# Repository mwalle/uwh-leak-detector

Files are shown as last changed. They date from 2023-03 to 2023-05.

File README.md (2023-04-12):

# Underwater Housing Leak Detector

Monitors the underpressure of your underwater housing and notifies you of
any leaks.

## Features

The leak detector provides the following features:

- Optical and acoustical alarm. Red and green LED to indicate the current
  health. Piezo buzzer to get the user's attention.
- Powered by just one CR2032 coin cell.
- Very long battery life, works down to 1.8V cell voltage.
- Battery monitoring. Indicates low-battery during idle mode.
- Hackable design using a Microchip ATtiny microcontroller
- MEMS pressure sensor. Supports two different devices: Bosch BMP581 and
  STMicro LPS22HB.
- Demo mode. Test any changes by a simulated sensor.
- Optical UART debug mode. The red LED can be used as a serial port. The
  receiver consists of a photo transistor and a bipolar transistor in a
  darlington configuration and an UART-to-USB adapter.
- Different modes selectable by the reset button.
- Extremely small.
- Open Hardware and Open Firmware schematics and layout as well as firmware
  sources are free for everyone.

## User's manual

TBD

## Mode of operation

Most functionality revolves around the microcontroller polling the pressure
sensor at a low frequency and then go (back) to sleep. The goal is to be in
sleep mode most of the time to save precious battery power. The
microcontroller runs with a system clock of 1MHz. The assumption is that a
slower clock frequency will preserve more power. But it is not clear whether
this is true; it might as well save more power if the microcontroller can
go back to sleep faster. One would need to do power consumption
measurements to evaluate which is better.

There are basically two different modes:
- Idle mode. The detector waits for a pressure drop to go into supervisor
  mode. In this mode, the pressure is polled every two seconds.
- Supervisor mode. The detector monitors the pressure at a faster rate and
  drives the dual-color LED/buzzer to show the state to the user.

Internally, the firmware consists of a [state
machine](firmware/main.c#L49). The state maps to the external indications
at any time. E.g. if the program is in state `ALARM`, the LED is flashing
red and the buzzer is enabled.

The firmware is able to count the number of reset button presses. Depending
on this the firmware enters different modes:
- Normal mode
- Debug mode. Red LED is used to transmit debug information.
- Demo mode. Instead of reading the real pressure, predefined measurements
  are replayed.
- Demo mode with debug. Combines demo and debug mode.
- Power-off mode. Turn off periodic watchdog interrupt. Only an external
  reset can wake up the microcontroller.

### ATtiny hardware block usage

The *Timer/Counter0* is used to stimulate the piezo buzzer with a 2kHz
frequency.

The *Timer/Counter1* is either used in PWM mode to dim the LEDs or to drive
the software UART. Both are mutually exclusive and the startup will choose
between these two.

The *Universal Serial Interface* is used for the I2C communication with the
pressure sensor. There is no receiving ACK handling (yet).

The *Watchdog timer* is used in interrupt mode as a wake up source. It will
wake up the microcontroller either every 250ms or every 2s, depending on
the mode. Additionally, it is used for timekeeping by counting ticks.

The *Analog to Digital Converter* is used in reverse mode (AREF is VCC and
the measurement is the internal band gap voltage) to measure the battery
voltage.

The *Analog Comparator` is unused and disabled on start-up.

The hardware is prepared to use interrupts via the *Pin Change Interrupt`
but it is unused. The sensor supports to constantly measure the pressure
and generate an interrupt if it is outside a predefined window. But it is
very limited in this regard, thus it not used for the time being.

### Supported pressure sensors

The firmware supports two different pressure sensors:
- [Bosch Sensortec
  BMP581](https://www.bosch-sensortec.com/products/environmental-sensors/pressure-sensors/bmp581/)
- [STMicroelectronics
  LPS22HB](https://www.st.com/en/mems-and-sensors/lps22hb.html)

They share the same footprint and can be used with the same PCB. The BMP581
is more advanced regarding its features, but most of them are unused. One
major drawback is the package and metal can of the sensor. There is a tiny
hole in the can which sometimes clogs and the sensor will measure bogus
values. Also, it isn't easy to convert the raw value of the sensor to
millibars. It will need division routines which takes up a lot of code
space.

The LPS22HB is a rather old sensor and consumes more power. It's package
doesn't have any holes but an exposed silicon area to sense the pressure.
Therefore, it is not prone to clogging like the BMP581. Also the register
interface seems to be more thought through. There are also successors of
the LPS22HB which need less power. Unfortunately, they aren't available at
the moment.

### Resource usage

TBD

## Programming the microcontroller

The board features a [Tag-Connect](https://www.tag-connect.com) with the
standard 6pin header AVR pinout. The microcontroller can be programmed
using the simple SPI based programming protocol. There is no need for
high-voltage programming.

## Schematics

The schematics are available [here](hardware/leak-detector.pdf).

## Bill Of Materials

| Ref | Qty | Part | Footprint |
| --- | --- | --- | --- |
| R1 | 1 | 33Ω Resistor | 0603 |
| R2, R7 | 2 | 1kΩ Resistor | 0603 |
| R3 | 1 | 10Ω Resistor | 0603 |
| R4, R5 | 2 | 100Ω Resistor | 0603 |
| R6, R8, R9 | 3 | 10kΩ Resistor | 0603 |
| D1 | 1 | Dual-color LED | - |
| U1 | 1 | BMP581/LPS22HB pressure sensor | LGA-10 |
| U2 | 1 | ATtiny25V | SOIC-8 |
| SW2 | 1 | PTS810 Push Button | - |
| BT1 | 1 | CR2032 Coin Cell Holder | - |
| BZ1 | 1 | Visaton 3580 Piezo Buzzer | - |

## Kits and PCBs

If you need a PCB, a kit or an assembled and pre-programmed board, contact
me at <uwh-leak-detector@walle.cc>.

## License

The schematics and layout is licensed under the CERN-OHL-S v2. The firmware
source is licensed under the GNU General Public License v3.0.

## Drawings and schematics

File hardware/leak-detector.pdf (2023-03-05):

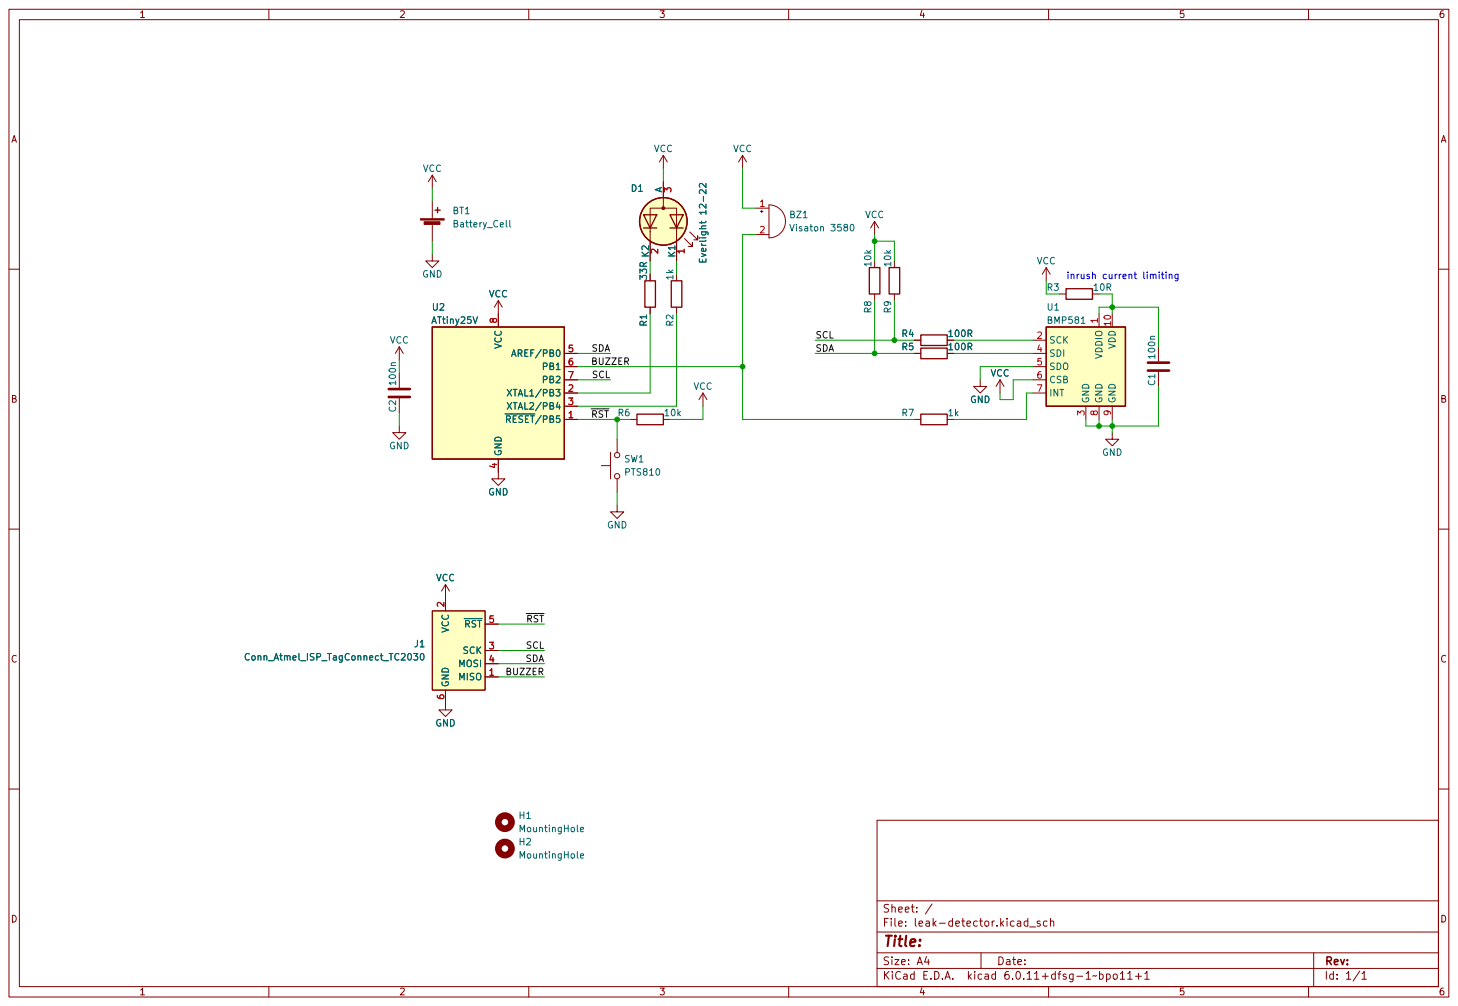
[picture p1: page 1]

Id: 1/1 Title: File: leak-detector.kicad_sch Sheet: / GND

2 SCK 3 MOSI 4 ~{RST}5 GND

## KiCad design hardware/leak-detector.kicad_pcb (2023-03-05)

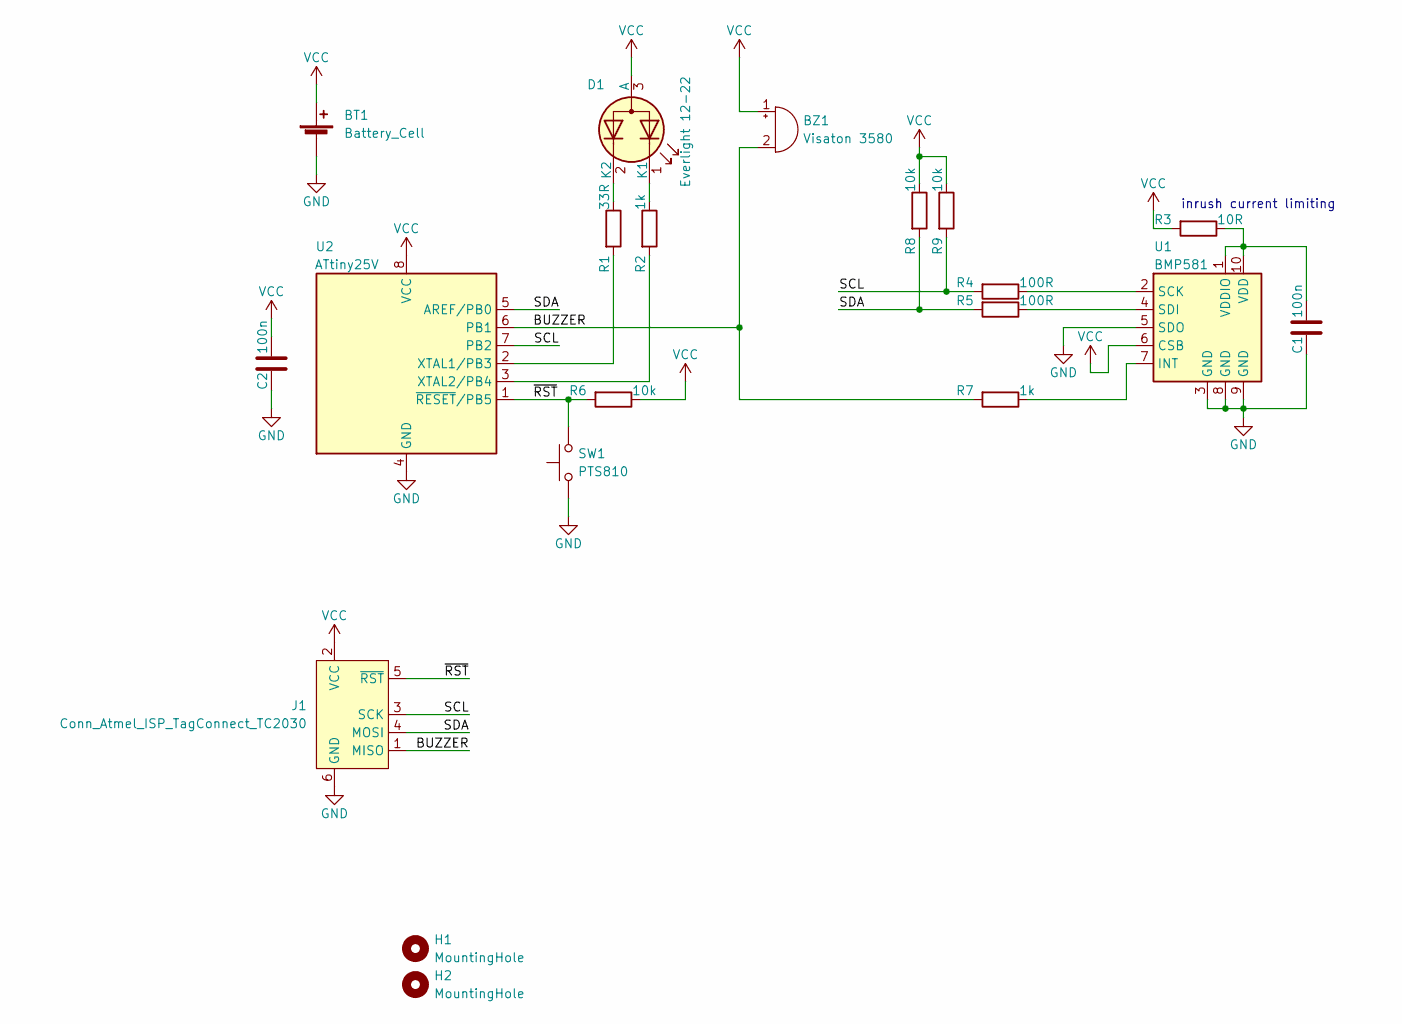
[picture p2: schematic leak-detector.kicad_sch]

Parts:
BT1: Battery_Cell; BatteryHolder_Keystone_2899_1x2032
BZ1: Visaton 3580; Buzzer_CUI_CPT-9019S-SMT
C1, C2: 100n; C_0603_1608Metric
D1: Everlight 12-22; LED_LiteOn_LTST-S326
H1, H2: MountingHole; MountingHole_2.7mm_M2.5
J1: Conn_Atmel_ISP_TagConnect_TC2030; Tag-Connect_TC2030-IDC-NL_2x03_P1.27mm_Vertical
R1: 33R; R_0603_1608Metric
R2, R7: 1k; R_0603_1608Metric
R3: 10R; R_0603_1608Metric
R4, R5: 100R; R_0603_1608Metric
R6, R8, R9: 10k; R_0603_1608Metric
SW1: PTS810; SW_SPST_PTS810
U1: BMP581; Bosch_LGA-10_2x2mm_P0.5mm
U2: ATtiny25V; SOIC-8_5.275x5.275mm_P1.27mm

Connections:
/BUZZER: BZ1.2 (+), J1.1 (MISO), R7.2, U2.6 (PB1)
/SCL: J1.3 (SCK), R4.2, R9.2, U2.7 (PB2)
/SDA: J1.4 (MOSI), R5.2, R8.2, U2.5 (AREF/PB0)
/~RST: J1.5 (~RST), R6.2, SW1.2, U2.1 (~RESET/PB5)
GND: BT1.2 (-), C1.2, C2.2, J1.6 (GND), SW1.1, U1.3 (GND), U1.5 (SDO), U1.8 (GND), U1.9 (GND), U2.4 (GND)
unnamed: C1.1, R3.1, U1.1 (VDDIO), U1.10 (VDD)
unnamed: D1.1 (K1), R2.1
unnamed: D1.2 (K2), R1.1
unnamed: R1.2, U2.2 (XTAL1/PB3)
unnamed: R2.2, U2.3 (XTAL2/PB4)
unnamed: R4.1, U1.2 (SCK)
unnamed: R5.1, U1.4 (SDI)
unnamed: R7.1, U1.7 (INT)
VCC: BT1.1 (+), BZ1.1 (-), C2.1, D1.3 (A), J1.2 (VCC), R3.2, R6.1, R8.1, R9.1, U1.6 (CSB), U2.8 (VCC)

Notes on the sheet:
inrush current limiting

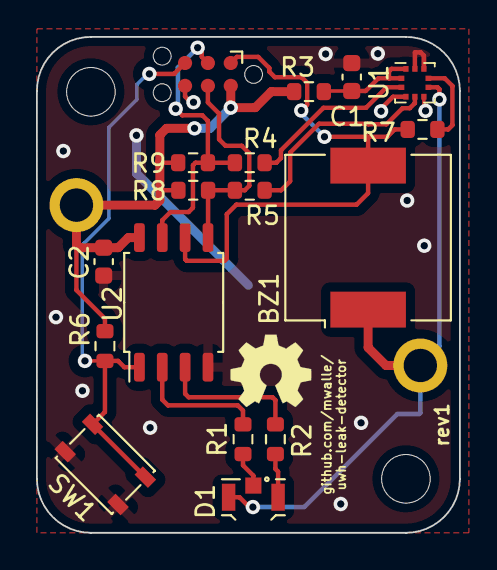
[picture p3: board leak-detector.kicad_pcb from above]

Board: 2 copper layers, 23.5 x 27.5 mm, 20 parts (1 on the bottom side), 14 nets.

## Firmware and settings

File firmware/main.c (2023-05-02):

/*
 * SPDX-License-Identifier: GPL-3.0-or-later
 *
 * lead-detector - simple pressure based leak detector
 *
 * Copyright (c) 2023, Michael Walle <michael@walle.cc>
 */

#include <stdio.h>
#include <stdbool.h>
#include <string.h>
#include <stdlib.h>
#include <avr/interrupt.h>
#include <avr/io.h>
#include <avr/pgmspace.h>
#include <avr/power.h>
#include <avr/sleep.h>
#include <avr/wdt.h>
#include <util/atomic.h>
#include <util/delay.h>

#include "config.h"
#include "twi.h"
#include "swuart.h"
#include "sensor.h"

#define STR(s) _STR(s)
#define _STR(s) #s

#ifdef VERSION
#ifdef GIT_HASH
#define VERSION_STR STR(VERSION) "-g" STR(GIT_HASH)
#else
#define VERSION_STR VERSION
#endif
#else
#define VERSION_STR "dev"
#endif

/* one tick is 250ms */
#define HZ 4

/* hyst of 10mbar for the alarm limit and 100mbar for turn on limit */
#define P_HYST_ALARM	10
#define P_HYST_IDLE	30
#define P_HYST_ON_OFF	100

#define IDLE_TIMEOUT	(60 * HZ)

#define BUZZER_HZ 2000

#define MILLIVOLTS(v)		((uint32_t)1100 * 256 / (v))
#define TO_CENTIVOLTS(v)	(110 * 256 / (v))
#define VBAT_LOW	MILLIVOLTS(2700)

#define LED_BLINKING	(1 << 0)
#define LED_ALTERNATING	(1 << 1)
#define LED_GREEN	(1 << 2)
#define LED_RED		(1 << 3)
#define BUZZER_ON	(1 << 4)

enum state {
	/*
	 * Device was woken up by the pressure sensor and is now constantly
	 * sampling the pressure. On device reset the current pressure is saved
	 * as the "normal" value. There is a window around this normal value
	 * where it is considered that the sensor is not in use. If after some
	 * time, the pressure is still in this window, the state is
	 * transitioned back to the POWERED_DOWN state. If the safe pressure
	 * threshold is reached though, the state transition to PRESSURE_OK.
	 */
	IDLE = LED_GREEN | LED_BLINKING,
	IDLE_BAT_LOW_DETECTED = LED_RED | LED_ALTERNATING,

	/*
	 * Device is powered-down, all clocks are turned off. Wake-up source is
	 * the watchdog interrupt. The watchdog interval is set to 2s to consume
	 * power. If the pressure is below the on-off threshold, the state will
	 * transition to to IDLE.
	 */
	POWERED_DOWN = 0,

	/*
	 * Device constantly measures the pressure. Pressure is only allowed to
	 * go down (with a hysteresis). If the pressure goes up, a leak is
	 * detected and the state transitions to ALARM.
	 */
	PRESSURE_OK = LED_GREEN,

	/*
	 * Device detected a leak. If pressure reaches the "normal" value
	 * window again, the state transisitons to IDLE. After 10s, the state
	 * automatically transition to SILENT_ALARM.
	 */
	ALARM = BUZZER_ON | LED_RED | LED_BLINKING,

	/* Same as ALARM. */
	SILENT_ALARM = LED_RED | LED_BLINKING,

	ERROR = LED_RED,
};

struct context {
	uint16_t ticks;
	uint16_t p;
	uint16_t p_idle;
	uint16_t p_on_off;
	uint16_t p_alarm;
	uint8_t vbat;
	uint8_t buzzer_off;
};

#define F_DEBUG (1 << 0)
#define F_DEMO (1 << 1)
#define F_BAT_LOW_DETECTED (1 << 2)
#define F_POWER_OFF (1 << 3)

/*
 * ticks will count the time since the last power-down (or start-up).
 * The watchdog timer period is 250ms, which gives us approximately
 * 4.5 hours (2^16 * 250ms) runtime until the counter overflows.
 **/
static volatile uint16_t __ticks;

/*
 * rstcnt will increase on every external reset, that is on every reset button
 * press. After ~400ms the counter is reset to zero. rstcnt is also cleared on
 * a power-on reset. It is used to determine run mode of the leak detector.
 */
static volatile uint8_t rstcnt __attribute__ ((section (".noinit")));

static uint8_t state;
static uint8_t flags;

ISR(WDT_vect)
{
	__ticks++;
}

static uint16_t get_ticks(void)
{
	uint16_t _ticks;
	ATOMIC_BLOCK(ATOMIC_FORCEON) {
		_ticks = __ticks;
	}
	return _ticks;
}

static void zero_ticks(void)
{
	ATOMIC_BLOCK(ATOMIC_FORCEON) {
		__ticks = 0;
	}
}

static void led_tick(void)
{
	uint8_t set = 0;

	if (flags & F_DEBUG)
		return;

	if (state)
		/* /8 prescaler */
		TCCR1 = _BV(CS12);
	else
		TCCR1 = 0;

	if (state & LED_RED)
		set = _BV(PB3);
	if (state & LED_GREEN)
		set = _BV(PB4);
	if (__ticks & 3) {
		if (state & LED_BLINKING)
			set = 0;
		if (state & LED_ALTERNATING)
			set = _BV(PB4);
	}

	DDRB &= ~(_BV(PB3) | _BV(PB4));
	DDRB |= set;
}

static void buzzer_tick(void)
{
	if (state & BUZZER_ON) {
		TCCR0B |= _BV(CS01);
		if (__ticks & 0x2)
			DDRB |= _BV(PB1);
		else
			DDRB &= ~_BV(PB1);
	} else {
		TCCR0B &= ~_BV(CS01);
	}
}

static void buzzer_init(void)
{
	/* PWM mode, output active low, prescaler to 8 */
	TCCR0A = _BV(WGM01) | _BV(WGM00) | _BV(COM0B1);
	TCCR0B = _BV(WGM02);
	OCR0A = (F_CPU / 8 / BUZZER_HZ);
	OCR0B = (F_CPU / 8 / BUZZER_HZ / 2);

	/* enable pull-up resistor */
	PORTB |= _BV(PB1);
}

static void wdt_power_down_mode()
{
	/* set watchdog period to 2s */
	WDTCR = _BV(WDIE) | _BV(WDP2) | _BV(WDP1) | _BV(WDP0);
}

static void wdt_normal_mode()
{
	/* enable interrupt and set period to 250ms */
	WDTCR = _BV(WDIE) | _BV(WDP2);
}

static void wdt_init(void)
{
	/*
	 * Watchdog enable survives an external reset, so disable the watchdog
	 * first. Just to be sure, in case there was a malfunction in our
	 * program.
	 */
	wdt_disable();
	wdt_normal_mode();
}

static void power_off(void)
{
	TCCR0B |= _BV(CS01);
	DDRB |= _BV(PB1);
	_delay_ms(200);
	DDRB &= ~_BV(PB1);
	_delay_ms(100);
	DDRB |= _BV(PB1);
	_delay_ms(200);
	DDRB &= ~_BV(PB1);

	PORTB = 0;
	DDRB = 0;
	WDTCR &= ~_BV(WDIE);
	set_sleep_mode(SLEEP_MODE_PWR_DOWN);
	sleep_mode();
}

static void power_down(void)
{
	PORTB |= _BV(PB3);
	PORTB |= _BV(PB4);

	wdt_power_down_mode();
	set_sleep_mode(SLEEP_MODE_PWR_DOWN);
	sleep_mode();
	wdt_normal_mode();
}

static void idle_mode(void)
{
	set_sleep_mode(SLEEP_MODE_IDLE);
	sleep_mode();
}

static void print_status(struct context *ctx)
{
	char buf[8];

	if (!CONFIG_ENABLE_UART)
		return;

	if (!(flags & F_DEBUG))
		return;

	uart_puts_P(PSTR("t"));
	uart_puts(itoa(ctx->ticks, buf, 10));
	uart_puts_P(PSTR(" s"));
	uart_puts(itoa(state, buf, 10));
	uart_puts_P(PSTR(" f"));
	uart_puts(itoa(flags, buf, 10));
	uart_puts_P(PSTR(" p"));
	uart_puts(itoa(ctx->p, buf, 10));
	uart_puts_P(PSTR(" a"));
	uart_puts(itoa(ctx->p_alarm, buf, 10));
	uart_puts_P(PSTR(" o"));
	uart_puts(itoa(ctx->p_on_off, buf, 10));
	uart_puts_P(PSTR(" v"));
	/* The following assumes a valid range of the ctx->vbat */
	itoa(TO_CENTIVOLTS(ctx->vbat), buf, 10);
	uart_putc(buf[0]);
	uart_puts_P(PSTR("."));
	uart_puts(buf + 1);
	uart_puts_P(PSTR("\n"));
}

static void adc_init(void)
{
	/* Vref = Vcc, input = Vbg */
	ADMUX = _BV(MUX3) | _BV(MUX2) | _BV(ADLAR);
	_delay_ms(1);
	/* 128 kHz clock */
	ADCSRA = _BV(ADPS1) | _BV(ADPS0);
}

static uint8_t vbat_voltage(void)
{
	ADCSRA |= _BV(ADEN);
	_delay_ms(1);
	ADCSRA |= _BV(ADSC);
	loop_until_bit_is_clear(ADCSRA, ADSC);
	ADCSRA &= ~_BV(ADEN);

	return ADCH;
}

static void trigger_state_machine(struct context *ctx)
{
	switch (state) {
	case POWERED_DOWN:
		zero_ticks();
		if (ctx->p < ctx->p_idle)
			state = IDLE;
		break;
	case IDLE:
		if (flags & F_BAT_LOW_DETECTED)
			state = IDLE_BAT_LOW_DETECTED;
		/* fallthrough */
	case IDLE_BAT_LOW_DETECTED:
		if (ctx->p < ctx->p_on_off) {
			ctx->p_alarm = ctx->p + P_HYST_ALARM;
			state = PRESSURE_OK;
		} else if (ctx->ticks >= IDLE_TIMEOUT) {
			state = POWERED_DOWN;
		}
		break;
	case PRESSURE_OK:
		if (ctx->p > ctx->p_alarm) {
			ctx->buzzer_off = 10 * HZ;
			state = ALARM;
		} else if (ctx->p + P_HYST_ALARM < ctx->p_alarm) {
			ctx->p_alarm = ctx->p + P_HYST_ALARM;
		}
		break;
	case ALARM:
		if (!(--ctx->buzzer_off))
			state = SILENT_ALARM;
		/* fallthrough */
	case SILENT_ALARM:
		if (ctx->p > ctx->p_on_off) {
			ctx->p_alarm = 0;
			state = IDLE;
		}
		break;
	}
}

void led_init(void)
{
	if (flags & F_DEBUG)
		return;

	/* 50% duty cycle */
	OCR1B = F_CPU / 8 / 2000 / 2;
	OCR1C = F_CPU / 8 / 2000;

	/* PWM mode, enable OC1B and OC1B# outputs, /8 prescaler */
	GTCCR = _BV(PWM1B) | _BV(COM1B0);
}

static void battery_check(struct context *ctx)
{
	ctx->vbat = vbat_voltage();
	/* vbat will increase with lower voltage */
	if (ctx->vbat > VBAT_LOW)
		flags |= F_BAT_LOW_DETECTED;
}

static void selftest(struct context *ctx)
{
	if (flags & F_DEBUG)
		return;

	/* enable timer for LEDs and buzzer */
	TCCR0B |= _BV(CS01);
	TCCR1 = _BV(CS12);

	DDRB |= _BV(PB4);
	_delay_ms(500);
	DDRB &= ~_BV(PB4);
	DDRB |= _BV(PB3);
	_delay_ms(500);
	battery_check(ctx);
	DDRB &= ~_BV(PB3);

	/* buzzer */
	DDRB |= _BV(PB1);
	_delay_ms(200);
	DDRB &= ~_BV(PB1);
}

static void error(void)
{
	cli();
	state = ERROR;
	led_tick();
	set_sleep_mode(SLEEP_MODE_PWR_DOWN);
	sleep_mode();
}

static void print_banner(struct sensor_driver *drv)
{
	if (!CONFIG_ENABLE_UART)
		return;

	if (!(flags & F_DEBUG))
		return;

	uart_puts_P(PSTR("leak-detector v" VERSION_STR " ("));
	uart_puts(drv->name);
	uart_puts_P(PSTR(")\n"));
}

int main(void)
{
	struct sensor_driver *drv = NULL;
	struct context ctx = { 0 };

	if (MCUSR & _BV(PORF))
		rstcnt = 0;
	MCUSR = 0;
	wdt_init();

	switch (++rstcnt) {
	case 3:
		flags = F_DEBUG;
		break;
	case 4:
		flags = F_DEMO;
		break;
	case 5:
		flags = F_DEMO | F_DEBUG;
		break;
	case 8:
		flags = F_POWER_OFF;
		break;
	}

	/* give the user some time to reset again */
	_delay_ms(400);
	rstcnt = 0;

	led_init();
	adc_init();
	buzzer_init();
	if (CONFIG_ENABLE_UART && flags & F_DEBUG)
		uart_init();

	if (CONFIG_ENABLE_DEMO && flags & F_DEMO)
		drv = &demo_driver;
	else if (CONFIG_ENABLE_BMP581 && sensor_is_present(&bmp581_driver))
		drv = &bmp581_driver;
	else if (CONFIG_ENABLE_LPS22HB && sensor_is_present(&lps22hb_driver))
		drv = &lps22hb_driver;

	if (!drv)
		error();

	sensor_init(drv);

	if (flags & F_POWER_OFF)
		power_off();

	/* disable unused blocks */
	ACSR |= _BV(ACD);

	selftest(&ctx);

	/*
	 * Clear watchdog flag, so the watchdog ISR won't be called right away
	 * and the ticks will start at zero.
	 */
	WDTCR |= _BV(WDIF);

	state = IDLE;
	sei();

	print_banner(drv);

	ctx.p = sensor_one_shot(drv);
	ctx.p_idle = ctx.p - P_HYST_IDLE;
	ctx.p_on_off = ctx.p - P_HYST_ON_OFF;

	while (true) {
		ctx.ticks = get_ticks();
		ctx.p = sensor_read_pressure(drv);

		/* every 8 seconds */
		if ((ctx.ticks & 0x1f) == 0)
			battery_check(&ctx);

		trigger_state_machine(&ctx);

		buzzer_tick();
		led_tick();

		/* every second */
		if ((ctx.ticks & 0x3) == 0)
			print_status(&ctx);

		/* Trigger the pressure measurment while we sleep */
		sensor_start_measurement(drv);

		/*
		 * This will either return on a watchdog interrupt, which means
		 * the device slept for 250ms or on any other interrupt, if the
		 * device is in idle mode. In the latter case, go back to idle
		 * mode until ticks has increased, to make sure, the main loop
		 * is only run once every tick.
		 */
		if (state == POWERED_DOWN)
			power_down();
		else
			while (get_ticks() == ctx.ticks)
				idle_mode();
	};

	return 0;
}

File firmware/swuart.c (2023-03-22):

/*
 * SPDX-License-Identifier: GPL-3.0-or-later
 *
 * Copyright (c) 2023, Michael Walle <michael@walle.cc>
 */

#include <stdbool.h>
#include <string.h>
#include <avr/io.h>
#include <avr/interrupt.h>
#include <avr/pgmspace.h>

#include "swuart.h"

static volatile uint16_t tx_char;
static volatile uint8_t tx_cnt;

#define BAUD 9600

ISR(TIM1_COMPA_vect)
{
	if (tx_char & 1)
		PORTB |= _BV(PB3);
	else
		PORTB &= ~_BV(PB3);
	tx_char >>= 1;

	if (--tx_cnt == 0)
		TCCR1 &= ~_BV(CS10); /* stop timer1 */
}

void uart_init(void) {
	/* turn output on */
	PORTB |= _BV(PB3);
	DDRB |= _BV(PB3);

	OCR1A = ((uint8_t)((F_CPU / BAUD) + 0.5)) - 1;
	OCR1C = ((uint8_t)((F_CPU / BAUD) + 0.5)) - 1;
	TIMSK |= _BV(OCIE1A); /* enable compare interrupt */
	TCCR1 = _BV(CTC1); /* CTC mode */
}

void uart_putc(const char c)
{
	if (c == '\n')
		uart_putc('\r');

	tx_char = 0x1801 | c << 2;
	tx_cnt = 13;

	TCNT1 = 0;

	/* now start the timer, everything else will be interrupt driven */
	TCCR1 |= _BV(CS10); /* start Timer1, no prescaler */

	/* loop until timer is disabled */
	loop_until_bit_is_clear(TCCR1, CS10);
}

void uart_puts(const char *s)
{
	while (*s)
		uart_putc(*(s++));
}

void uart_puts_P(const char *s)
{
	char c;
	while ((c = pgm_read_byte(s++)))
		uart_putc(c);
}

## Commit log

2023-03-05 hardware: initial commit
    [leak-detector.kicad_pcb, leak-detector.kicad_sch]
2023-03-14 firmware: add ADC support
    Add battery voltage tracking. Use the external Vcc (the battery voltage)
    as reference and measure the internal bandgap voltage. Then use the
    inverse function of the ADC formulae to infer the battery voltage.
2023-03-16 firmware: swuart: use 9600 baud
    It turns out, the hardware is able to go faster. 9600 baud seems to on
    the edge what is possible to do with the 1MHz system clock and software
    UART.
2023-03-16 firmware: sensor OOR mode and major rework
    Add support for the out-of-range mode of the pressure sensor. The idea
    is that the sensor could wake the µC and the µC doesn't have to poll the
    sensor periodically. Unfortunately, the sensor is only able the maximum
    range is just about +/-2.55mbar.
    Also document our states, move the state handling into a function.
    [main.c]
2023-03-16 firmware: adc: only enable ADC during measurement
    The battery voltage is just measured once in a while. Enable the ADC
    block only when needed.
2023-03-16 firmware: bmp581: remove OOR mode
    It turns out, the mode doesn't work reliably. Let the µC just poll the
    sensor in power down mode.
    [main.c]
2023-03-16 firmware: buzzer: use timer0 and add buzzer_init()
    Now that timer1 is used by the software UART, use timer0 for the buzzer.
    Also, move the timer setup into buzzer_init() and only enable and
    disable the timer and output in buzzer_{on,off}().
    [main.c]
2023-03-16 firmware: led: rework LED handling
    Introduce led_init() and don't use update_led() in the selftest. Instead
    let the selftest set the appropriate bits itself.
    [main.c]
2023-03-16 firmware: mainloop: poll the pressure in powered-down mode
    If the pressure is within the "normal" range. Reconfigure the watchdog
    to just wake the µC up every 2s to poll the pressure. Introduce a new
    threshold p_on_off to move into idle mode if it's exceeded.
2023-03-16 firmware: rework print_status()
2023-03-16 firmware: mainloop: trigger sensor read before power-down
    Instead of waiting for the sensor to complete the measurement within the
    active cycle, just start a measurement at the end and read the results
    at the start of the next cycle.
2023-03-16 firmware: swuart: change to timer1
    Use timer1 for the swuart. The timer1 needs more power than timer0 and
    in normal mode, the UART isn't used. Thus, use timer1 for the UART.
    Timer0 can later be used to drive the LEDs in PWM mode.
2023-03-16 firmware: mainloop: go back to sleep if ticks haven't advanced
    Any interrupt might wake the µC. If the ticks didn't change, that is
    there was no watchdog interrupt. Just go back to sleep.
    [main.c]
2023-03-16 firmware: add demo sensor support
    Add a new demo mode. If activated, that sensor will return mocked values
    for the pressure reading.
    To activate that mode, the user has to reset the board four or five
    times in a row.
    [main.c]
2023-03-17 firmware: introduce sensor class
    Factor out all the sensor handling. Move the demo sensor into an own
    module. This way, additional sensor support only need to implement some
    sensor ops in its own module.
2023-03-17 firmware: move buzzer into own module
    Move the buzzer handling into an own module and get rid of the
    update_buzzer(). The buzzer module can use an ISR to toggle the buzzer
    itself.
    [main.c]
2023-03-17 firmware: setup: clear watchdog flag before enabling interrupts
    The watchdog flag might already be set before we use it and thus the
    watchdog timer ISR is immediately triggered after enabling interrupts.
    That will already increase the ticks by one. Avoid that by clearing that
    flag.
    [main.c]
2023-03-17 firmware: add low battery indication
    The battery is measure during each cycle. If the voltage is below 2.9V
    set a flag which will change the LED pattern during idle mode to give
    the user an indication.
2023-03-17 firmware: add new silent alarm feature
    If a leak is detected the buzzer will be turned on. It is assumed that
    after some time, the user noticed the alarm and we can silence the
    beeper.
    [main.c]
2023-03-17 firmware: slightly rework print_status()
    [main.c]
2023-03-17 firmware: sensor: always return mbar
    Return sensor readings in mbar. This is the first step to support more
    than just one pressure sensor. All sensors will need to return the
    measurement in mbar. This will also simplify the code because the MBAR()
    and similar macros are not needed anymore. On the flipside, runtime
    division is now needed which increases the code size. But these routines
    are also needed for the status line printing.
    [main.c]
2023-03-18 firmware: introduce compile options
    Make it configurable to exclude individual components from compilation.
    Start with the software UART. The compiler will take care of optimizing
    away any unused code and the linker won't complain about missing
    function calls.
    [main.c]
2023-03-19 firmware: sensor: move one_shot() to sensor.h and convenience functions
    The one shot method can be implemented in the sensor class. There is no
    need that every sensor has its own implementation of it. While at it,
    provide handy sensor_*() functions.
2023-03-19 firmware: bmp581: just read two bytes pressure data
    No need to read all three bytes, if only two are used.
2023-03-19 firmware: support STM LPS22HB
    Add support for the STMicro LPS22HB pressure sensor.
2023-03-20 firmware: buzzer: enable pull-up resistor
    The pin might also be used as an open drain active-low interrupt line.
    Enable the pull-up because there is no external one.
2023-03-20 firmware: led: use PWM and make code smaller
    Use PWM for the LEDs to consume some power and make it the code smaller
    by encoding the LED control into the state variable.
2023-03-20 firmware: only call uart_init() when debug is enabled
2023-03-21 firmware: bmp581: remove temperature reading
    Remove the dead code.
2023-03-21 firmware: set the lower battery threshold to 2.7V
    CR2032 coin cells have around 10% capacity left when they reach 2.7V.
2023-03-21 firmware: don't track the led state
    Don't track the LED state, just update the LEDs every time.
2023-03-21 firmware: selftest: fix LED selftest
    With the recent PWM changes for the LEDs, a different handling for the
    selftest is needed.
    [main.c]
2023-03-21 firmware: battery: do the battery check during selftest
    Measure the battery voltage at the end of the LED selftest. This way,
    the battery will be stressed before doing the measurement.
2023-03-22 firmware: make individual sensors configurable
2023-03-22 firmware: display voltage as floating point
2023-03-22 firmware: buzzer: drop the ISR handling
    The ISR will disturb the software UART, which also use ISRs. Instead
    call the update routine from the watchdog ISR.
    [main.c]
2023-03-22 firmware: battery: measure voltage only every 8s
2023-03-22 firmware: move watchdog handling
    Move the watchdog period handling out of the state machine handling into
    power_down().
2023-03-22 firmware: move buzzer function from module to the main module
    [main.c]
2023-03-22 firmware: encode buzzer and led function into state
    Drop context::state and instead make it a global variable with a special
    encoding. This will save some code size.
    [main.c]
2023-03-22 firmware: move the buzzer_tick() and led_tick()
    Move the buzzer_tick() and led_tick() after the state machine
    processing, which will update the buzzer and LED after the state change.
    [main.c]
2023-04-04 firmware: introduce power-down mode
    Add a power-down mode to turn off everything which is possible. That is,
    turn off the watchdog and pin-change interrupts and go into sleep mode.
    The only wake up source is the reset button.
2023-05-02 firmware: add banner
    Print a banner with version and detected sensor at startup.
